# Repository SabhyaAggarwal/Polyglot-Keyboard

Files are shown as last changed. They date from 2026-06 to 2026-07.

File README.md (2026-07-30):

# Polyglot-Keyboard
This is a keyboard made by me that can change between stenography mode and QWERTY mode. It is basically a cheaper version of the [Polyglot Keyboard by Steno Keyboards](https://stenokeyboards.com/products/polyglot-keyboard). It uses the QMK Firmware. The PCB was made in KiCad. The case was designed in OnShape. It is quite effective and also very beautiful. The design and shape are customised for my personal use...

## BOM

|Name |Description |Quantity|Total Cost|Link |Distributor|
|---|---|---|---|---|---|
|PCB |Main PCB(includes payment fee) |1 |$1.36 |https://aivon.com/ |AIVON |
|RP2040 Zero |Main Dev Board(cost includes shipping) |1 |$4.73 |https://robu.in/product/waveshare-rp2040-zero-without-header/ |robu |
|MX Switches |MX switches(pack of 10 and 4 of them = 40 keys and rest 2 keys given by another HackClubber)|4 |$2.86 |https://meckeys.com/shop/accessories/keyboard-accessories/key-switches/regular-switch-3pin/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|meckeys |
|Keycaps |Blank Keycaps(pack of 5) |9 |$8.58 |https://meckeys.com/shop/accessories/keyboard-accessories/keycaps/blank/blank-dsa-keycaps-1u/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 |meckeys |
|1N4148 Diode |1N4148 Diode(price not include shipping as shipping is shared with the RP2040 Zero) |42 |$0.55 |https://robu.in/product/1n4148-1w-zener-diode-pack-of-50/ |robu |
|M3x3mm Heatset Insert|M3 X 3mm Brass Threaded Inserts(includes shipping cost) |3 |$0.94 |https://onlyscrews.in/products/m3-x-3mm-brass-threaded-inserts?variant=49729062273337 |onlyscrews |
|M3x5mm Screws |Screws(shipping grouped with inserts) |3 |$0.06 |https://onlyscrews.in/products/m3-x-5mm-phillips-pan-head-ss-304-screw-dia-3mm-length-5mm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 |onlyscrews |

## Images

### Keymap in Stenography mode

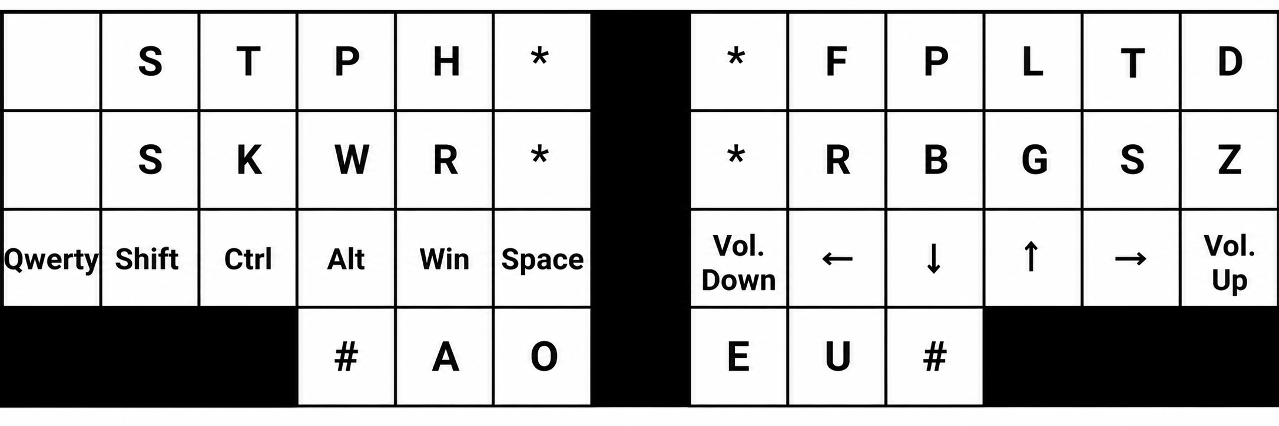
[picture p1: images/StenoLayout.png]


### Keymap in QWERTY mode

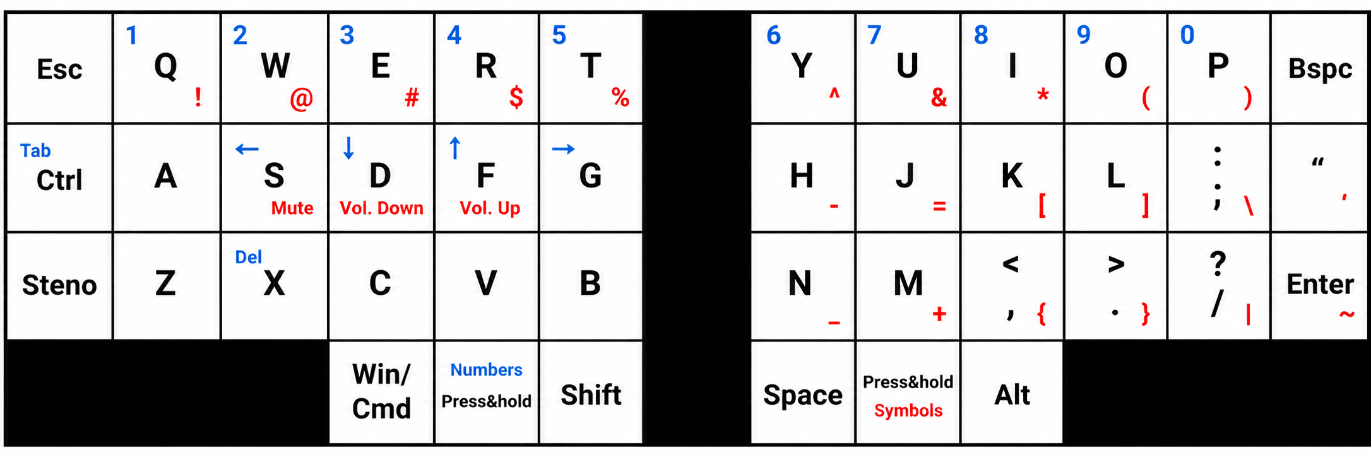
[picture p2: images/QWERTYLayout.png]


### 3D Render of the  assembled keyboard

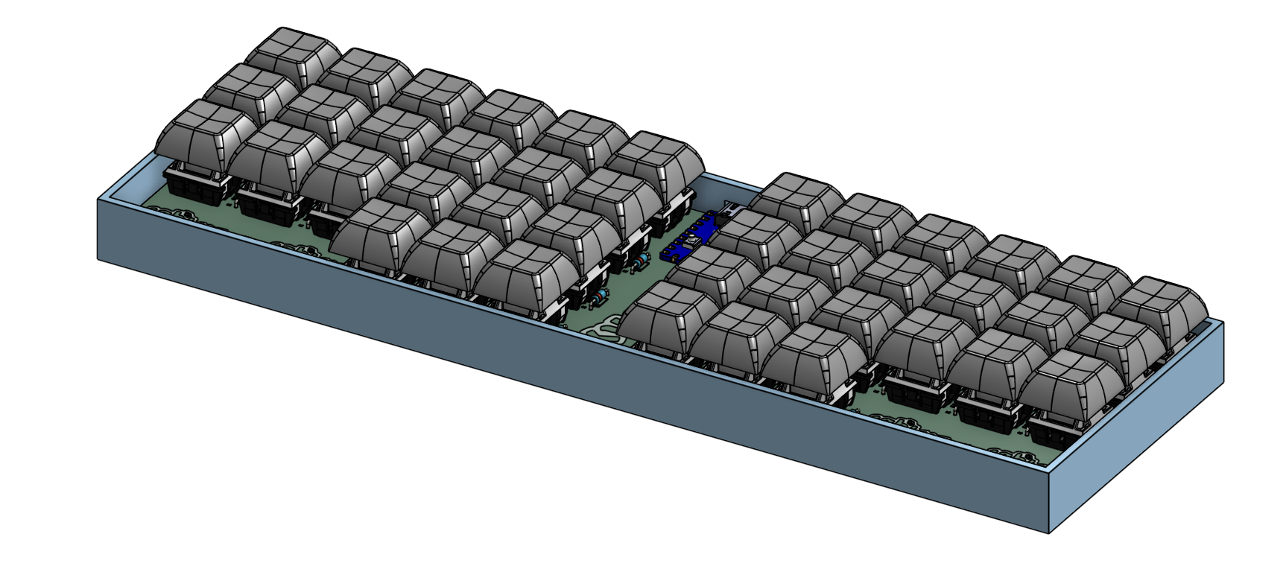
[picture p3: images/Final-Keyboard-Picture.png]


### Case

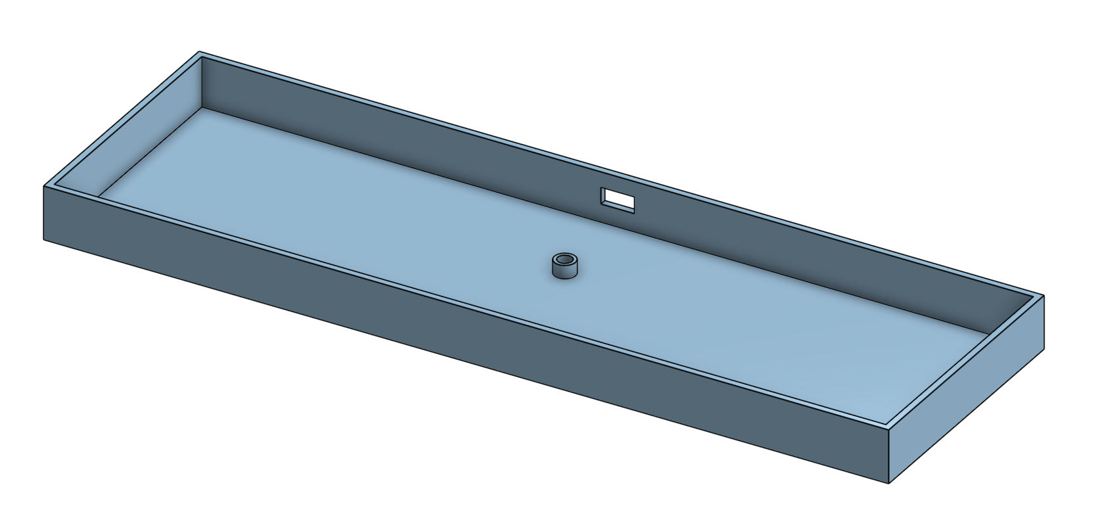
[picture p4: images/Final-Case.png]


#### Note: You can find the OnShape link [here](https://cad.onshape.com/documents/46c4256cf36649b9a784f734/w/7d5e5e40fb0c8f37601f916c/e/410489c67a58600f0a7678ff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)...

### PCB Schematic

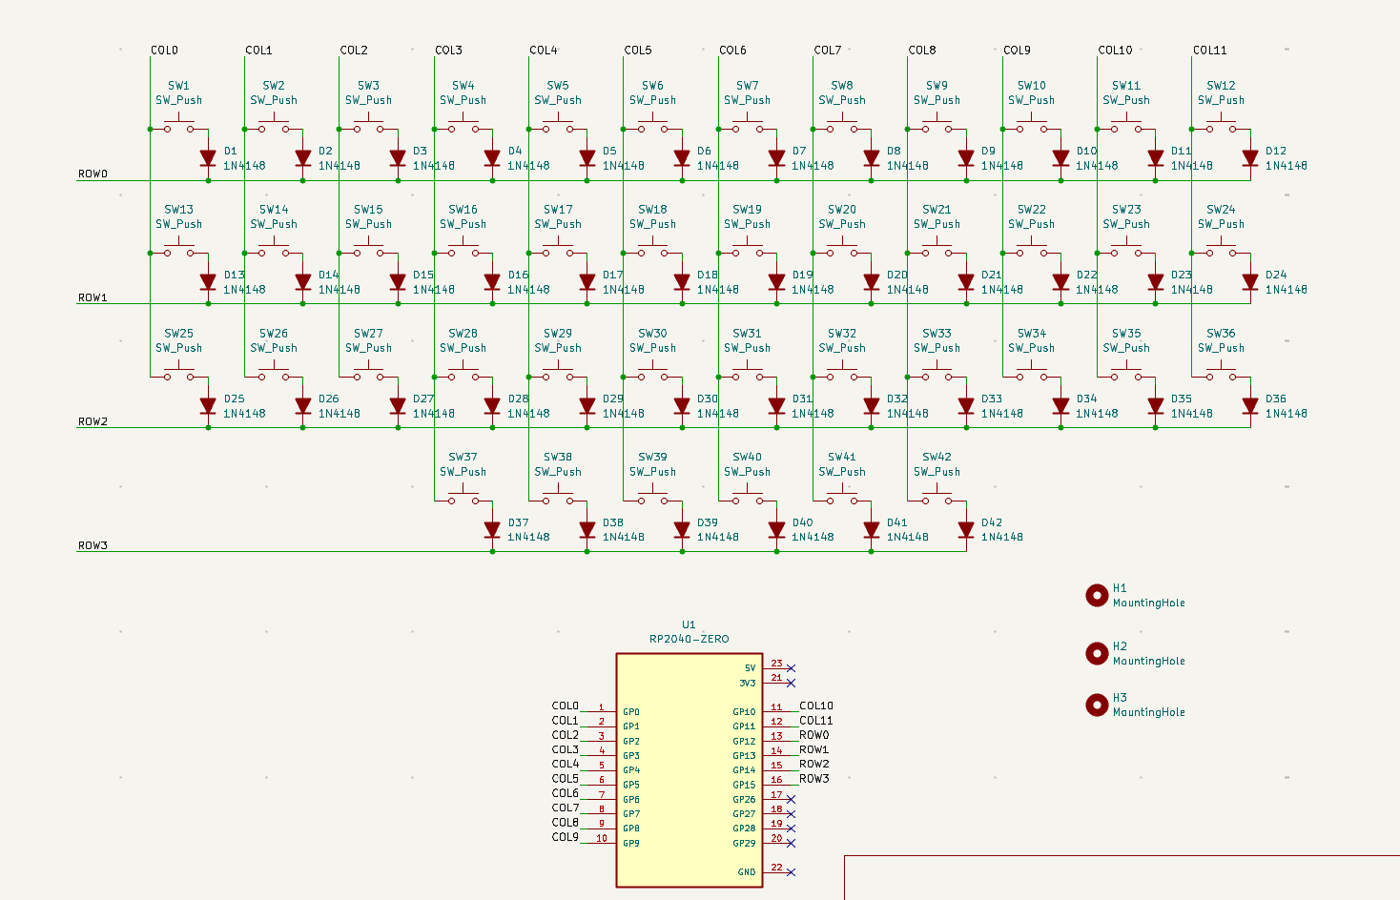
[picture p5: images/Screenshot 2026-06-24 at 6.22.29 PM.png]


### PCB Design

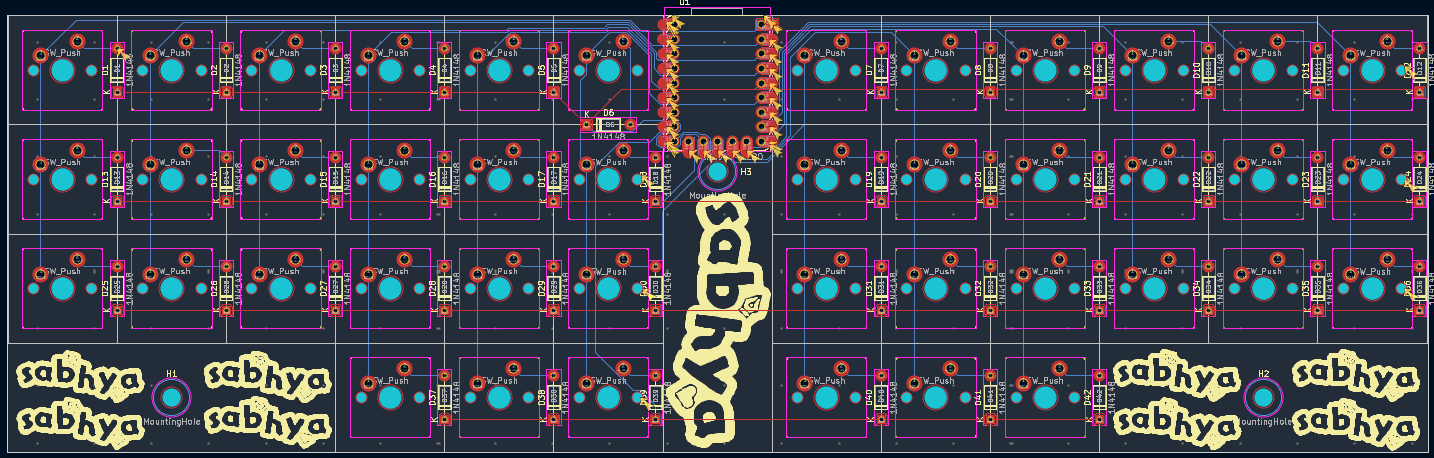
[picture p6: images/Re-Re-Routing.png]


### PCB 3D Render

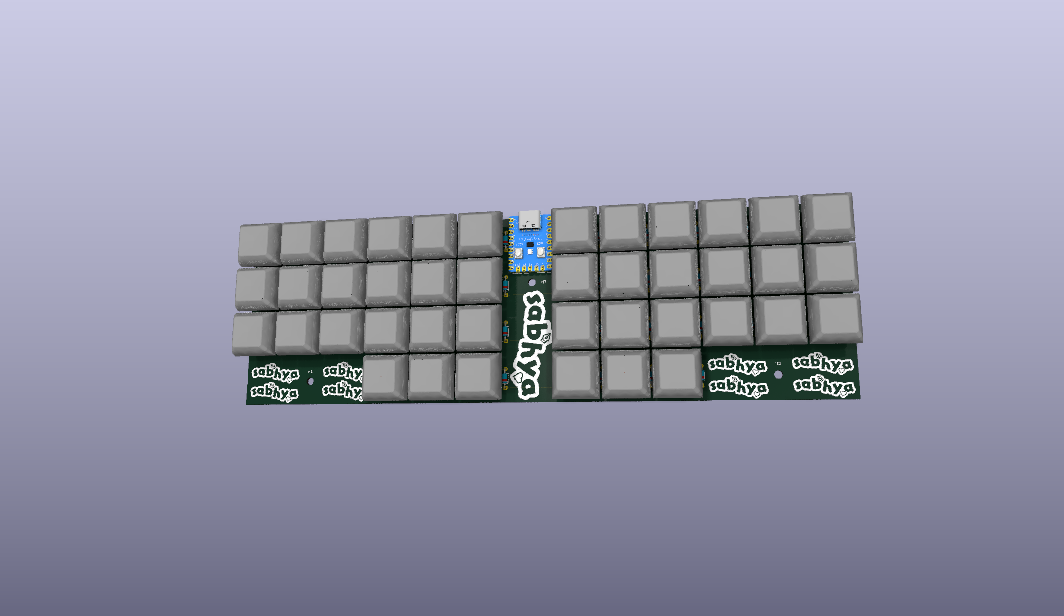
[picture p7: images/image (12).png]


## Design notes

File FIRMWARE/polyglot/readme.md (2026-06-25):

# polyglot

polyglot

*A short description of the keyboard/project*

* Keyboard Maintainer: [Sabhya Aggarwal](https://github.com/SabhyaAggarwal)
* Hardware Supported: *The PCBs, controllers supported*
* Hardware Availability: *Links to where you can find this hardware*

Make example for this keyboard (after setting up your build environment):

    make polyglot:default

Flashing example for this keyboard:

    make polyglot:default:flash

See the [build environment setup](https://docs.qmk.fm/#/getting_started_build_tools) and the [make instructions](https://docs.qmk.fm/#/getting_started_make_guide) for more information. Brand new to QMK? Start with our [Complete Newbs Guide](https://docs.qmk.fm/#/newbs).

## Bootloader

Enter the bootloader in 3 ways:

* **Bootmagic reset**: Hold down the key at (0,0) in the matrix (usually the top left key or Escape) and plug in the keyboard
* **Physical reset button**: Briefly press the button on the back of the PCB - some may have pads you must short instead
* **Keycode in layout**: Press the key mapped to `QK_BOOT` if it is available

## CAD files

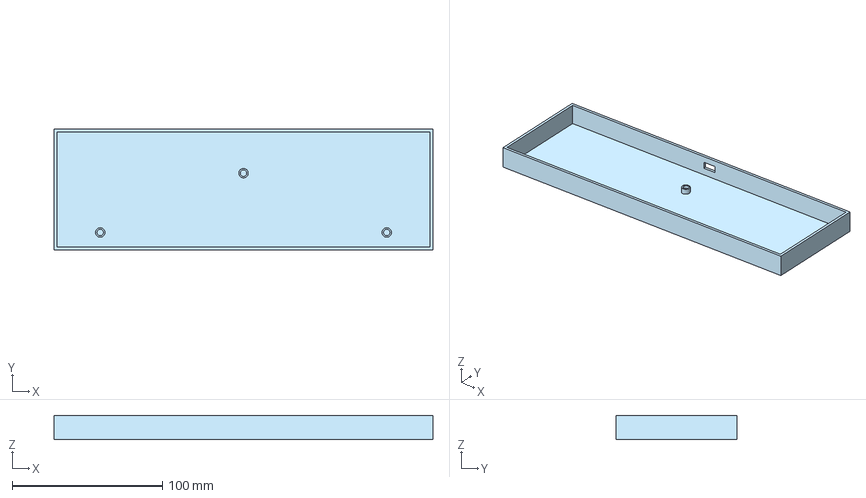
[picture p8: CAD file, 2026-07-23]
CAD/Case.step
252.0 x 80.3 x 16.0 mm

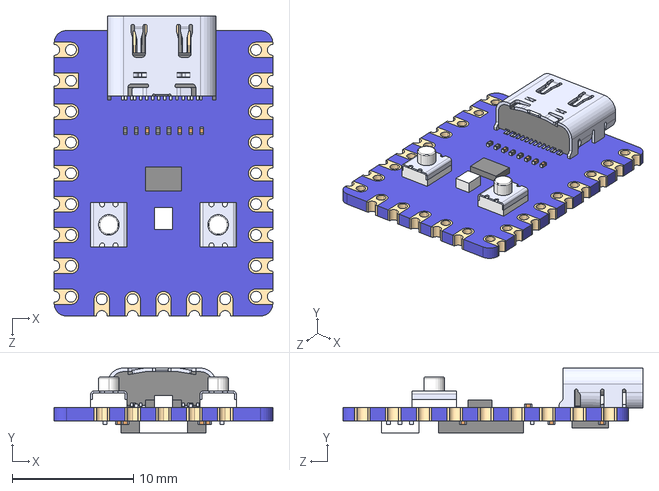
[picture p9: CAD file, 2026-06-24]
PCB/RP2040-ZERO.step
18.0 x 5.35 x 24.7 mm

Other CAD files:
PRODUCTION/Case.stl

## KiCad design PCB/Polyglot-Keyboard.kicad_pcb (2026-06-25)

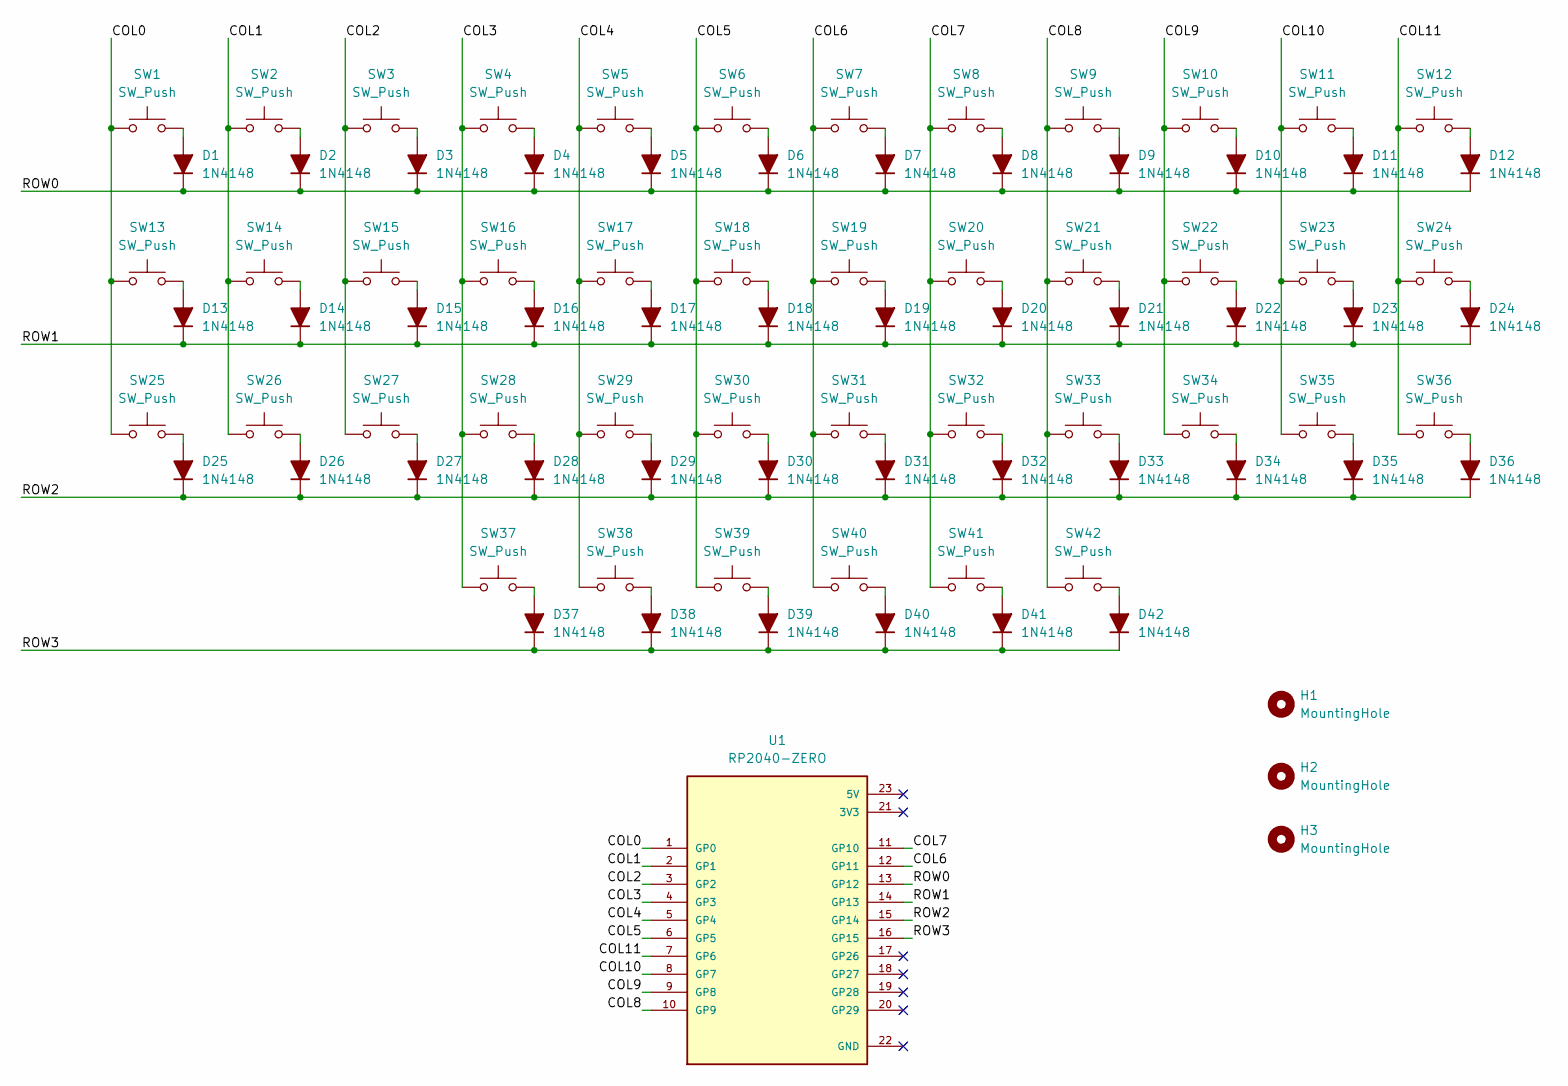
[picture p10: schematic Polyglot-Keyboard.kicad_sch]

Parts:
D1, D2, D3, D4, D5, D6, D7, D8, D9, D10, D11, D12, D13, D14, D15, D16, D17, D18, D19, D20, D21, D22, D23, D24, D25, D26, D27, D28, D29, D30, D31, D32, D33, D34, D35, D36, D37, D38, D39, D40, D41, D42: 1N4148; D_DO-35_SOD27_P7.62mm_Horizontal
H1, H2, H3: MountingHole; MountingHole_3.2mm_M3
SW1, SW2, SW3, SW4, SW5, SW6, SW7, SW8, SW9, SW10, SW11, SW12, SW13, SW14, SW15, SW16, SW17, SW18, SW19, SW20, SW21, SW22, SW23, SW24, SW25, SW26, SW27, SW28, SW29, SW30, SW31, SW32, SW33, SW34, SW35, SW36, SW37, SW38, SW39, SW40, SW41, SW42: SW_Push; SW_MX_1u
U1: RP2040-ZERO; MODULE_RP2040-ZERO; PARTREV NA

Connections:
/COL0: SW1.1, SW13.1, SW25.1, U1.1 (GP0)
/COL1: SW2.1, SW14.1, SW26.1, U1.2 (GP1)
/COL2: SW3.1, SW15.1, SW27.1, U1.3 (GP2)
/COL3: SW4.1, SW16.1, SW28.1, SW37.1, U1.4 (GP3)
/COL4: SW5.1, SW17.1, SW29.1, SW38.1, U1.5 (GP4)
/COL5: SW6.1, SW18.1, SW30.1, SW39.1, U1.6 (GP5)
/COL6: SW7.1, SW19.1, SW31.1, SW40.1, U1.12 (GP11)
/COL7: SW8.1, SW20.1, SW32.1, SW41.1, U1.11 (GP10)
/COL8: SW9.1, SW21.1, SW33.1, SW42.1, U1.10 (GP9)
/COL9: SW10.1, SW22.1, SW34.1, U1.9 (GP8)
/COL10: SW11.1, SW23.1, SW35.1, U1.8 (GP7)
/COL11: SW12.1, SW24.1, SW36.1, U1.7 (GP6)
/ROW0: D1.1 (K), D2.1 (K), D3.1 (K), D4.1 (K), D5.1 (K), D6.1 (K), D7.1 (K), D8.1 (K), D9.1 (K), D10.1 (K), D11.1 (K), D12.1 (K), U1.13 (GP12)
/ROW1: D13.1 (K), D14.1 (K), D15.1 (K), D16.1 (K), D17.1 (K), D18.1 (K), D19.1 (K), D20.1 (K), D21.1 (K), D22.1 (K), D23.1 (K), D24.1 (K), U1.14 (GP13)
/ROW2: D25.1 (K), D26.1 (K), D27.1 (K), D28.1 (K), D29.1 (K), D30.1 (K), D31.1 (K), D32.1 (K), D33.1 (K), D34.1 (K), D35.1 (K), D36.1 (K), U1.15 (GP14)
/ROW3: D37.1 (K), D38.1 (K), D39.1 (K), D40.1 (K), D41.1 (K), D42.1 (K), U1.16 (GP15)
unnamed: D1.2 (A), SW1.2
unnamed: D2.2 (A), SW2.2
unnamed: D3.2 (A), SW3.2
unnamed: D4.2 (A), SW4.2
unnamed: D5.2 (A), SW5.2
unnamed: D6.2 (A), SW6.2
unnamed: D7.2 (A), SW7.2
unnamed: D8.2 (A), SW8.2
unnamed: D9.2 (A), SW9.2
unnamed: D10.2 (A), SW10.2
unnamed: D11.2 (A), SW11.2
unnamed: D12.2 (A), SW12.2
unnamed: D13.2 (A), SW13.2
unnamed: D14.2 (A), SW14.2
unnamed: D15.2 (A), SW15.2
unnamed: D16.2 (A), SW16.2
unnamed: D17.2 (A), SW17.2
unnamed: D18.2 (A), SW18.2
unnamed: D19.2 (A), SW19.2
unnamed: D20.2 (A), SW20.2
unnamed: D21.2 (A), SW21.2
unnamed: D22.2 (A), SW22.2
unnamed: D23.2 (A), SW23.2
unnamed: D24.2 (A), SW24.2
unnamed: D25.2 (A), SW25.2
unnamed: D26.2 (A), SW26.2
unnamed: D27.2 (A), SW27.2
unnamed: D28.2 (A), SW28.2
unnamed: D29.2 (A), SW29.2
unnamed: D30.2 (A), SW30.2
unnamed: D31.2 (A), SW31.2
unnamed: D32.2 (A), SW32.2
unnamed: D33.2 (A), SW33.2
unnamed: D34.2 (A), SW34.2
unnamed: D35.2 (A), SW35.2
unnamed: D36.2 (A), SW36.2
unnamed: D37.2 (A), SW37.2
unnamed: D38.2 (A), SW38.2
unnamed: D39.2 (A), SW39.2
unnamed: D40.2 (A), SW40.2
unnamed: D41.2 (A), SW41.2
unnamed: D42.2 (A), SW42.2

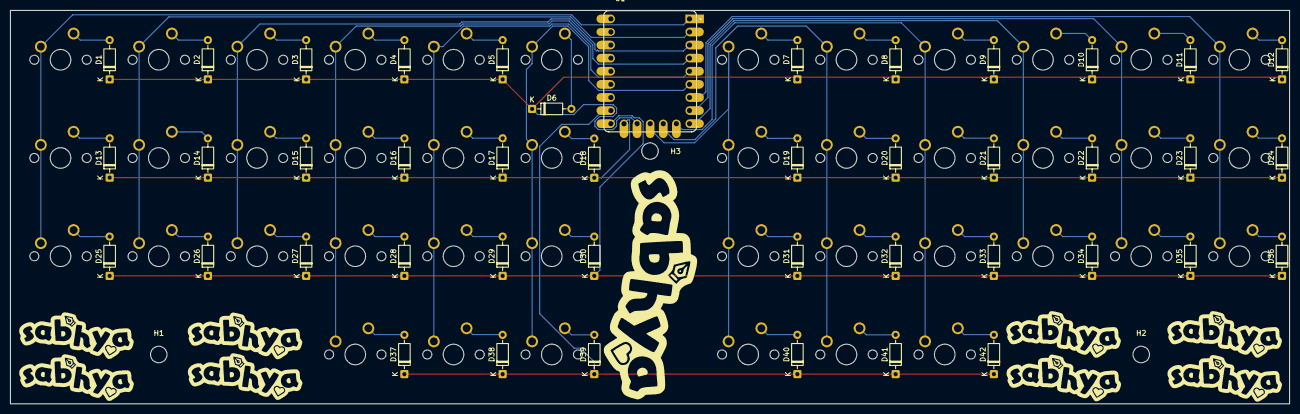
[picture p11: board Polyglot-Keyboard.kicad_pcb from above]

Board: 2 copper layers, 248.0 x 76.3 mm, 88 parts (0 on the bottom side), 58 nets.

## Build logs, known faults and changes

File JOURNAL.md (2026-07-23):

---
title: "Polyglot-Keyboard"
author: "Sabhya Aggarwal"
description: "A keyboard that can function as both a stenography keyboard and a QWERTY keyboard"
created_at: "2026-06-24"
---

# June 24: Made the schematic and PCB

So I explored the guide and decided how I wanted my PCB to be: a mixture of a tray mount and a plateless mount keyboard that supports stenography, which I want to try out, and also supports the QWERTY 

Schematic:

Schematic

and I made the PCB:

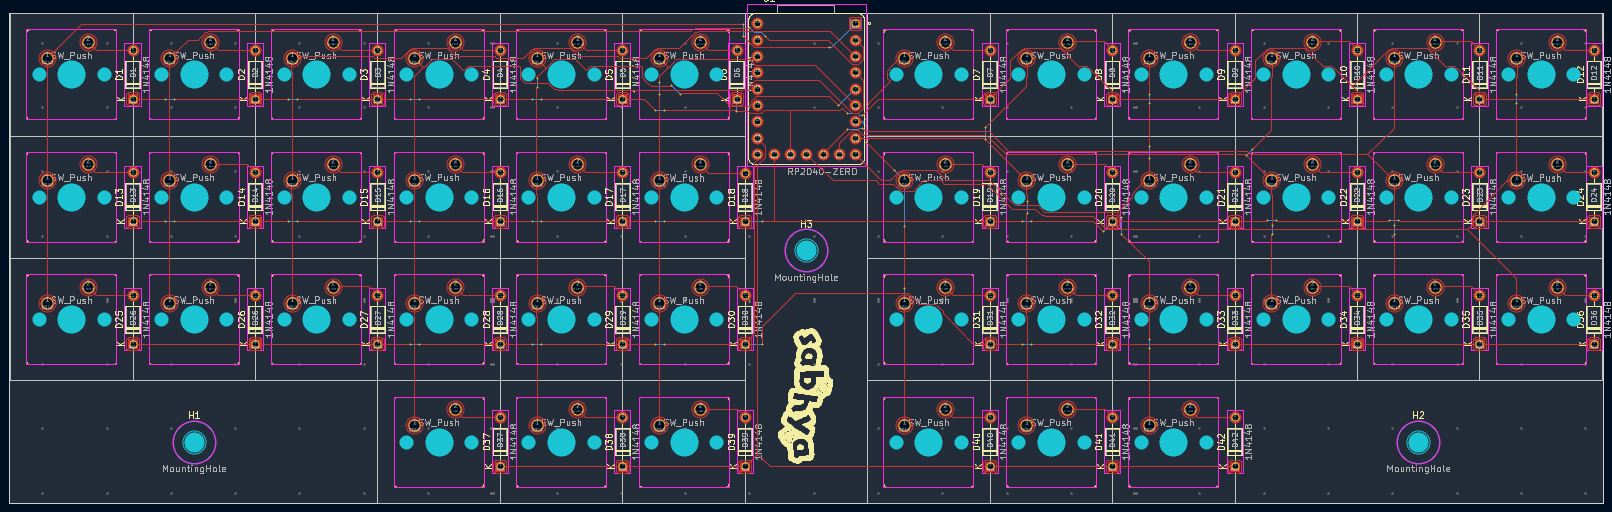
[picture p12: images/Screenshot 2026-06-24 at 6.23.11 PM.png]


Here is the beautiful 3d render of PCB:

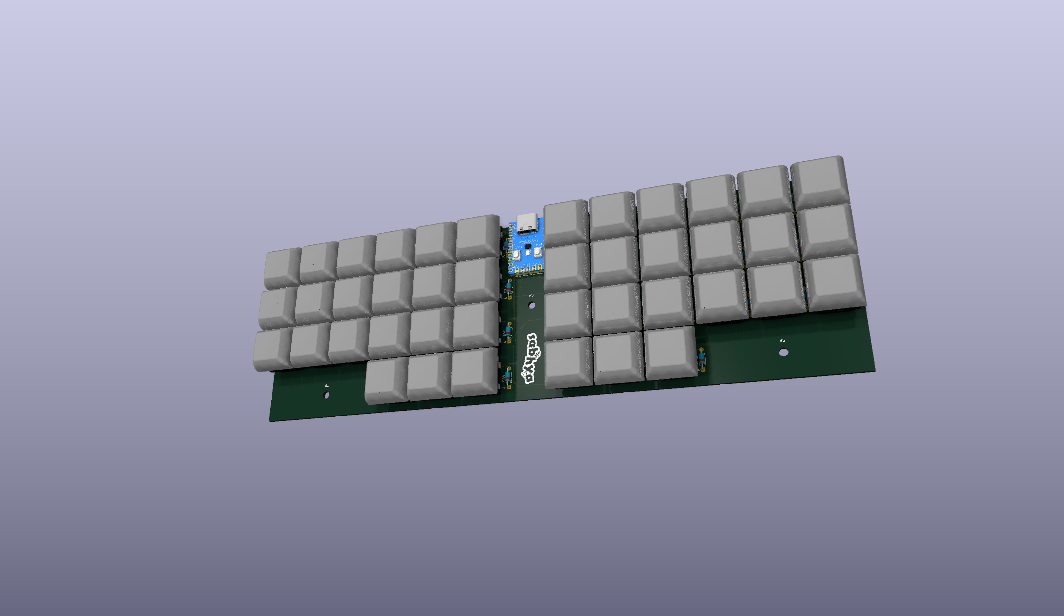
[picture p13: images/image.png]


**Total time spent: 7 hrs**

# June 24: Manually routed the board cleanly

So I found out that auto routing is not allowed so I manually routed everything and I made it cleanly. I had to modify the pinout, which GPIO pins are connected to which, because as I exchanged that I made the routing even cleaner. In the middle I remembered that I can use 2 layers. As I remembered that, I made my routing very beautiful and very good. Now my PCB looks great. I love it 

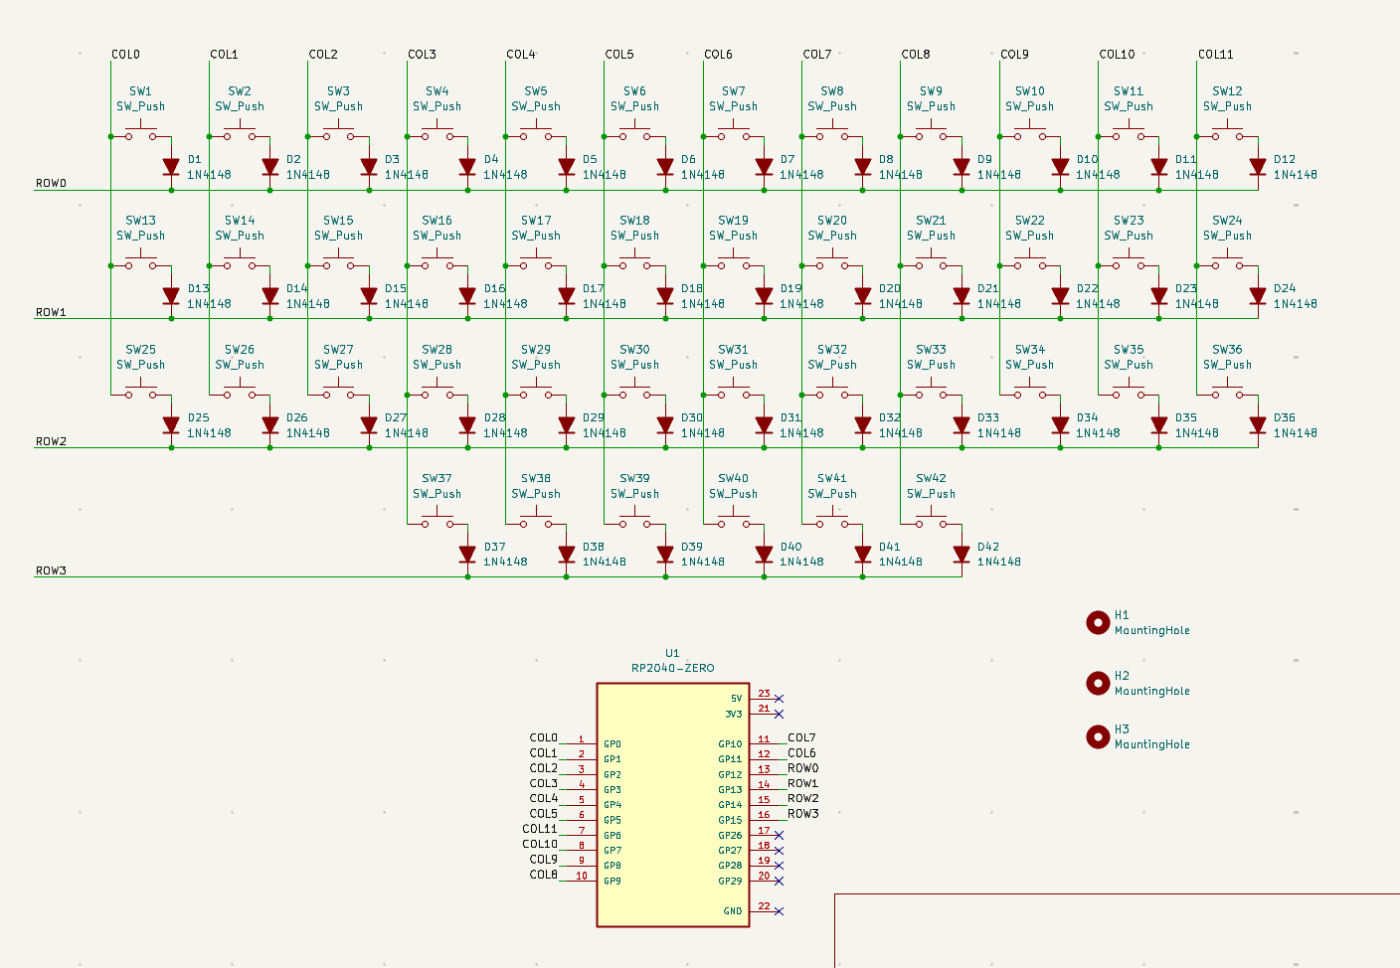
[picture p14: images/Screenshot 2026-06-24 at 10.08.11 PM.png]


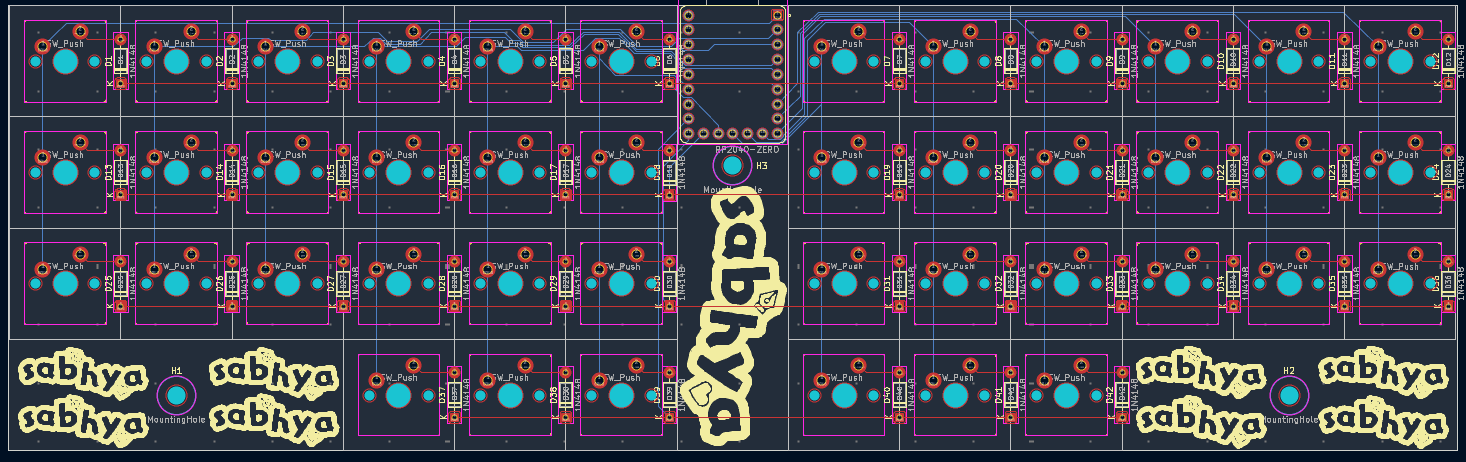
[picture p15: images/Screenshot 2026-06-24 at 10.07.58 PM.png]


3D render

**Total time spent: 3.7 hrs**

# June 25 : Fixed up the routing and all(again) and made Case and Firmware

Today was a really productive day. I decided that I am not going to use other things for the main dev board but rather I'll just directly solder it on through the castellated edges...

Old Footprint:

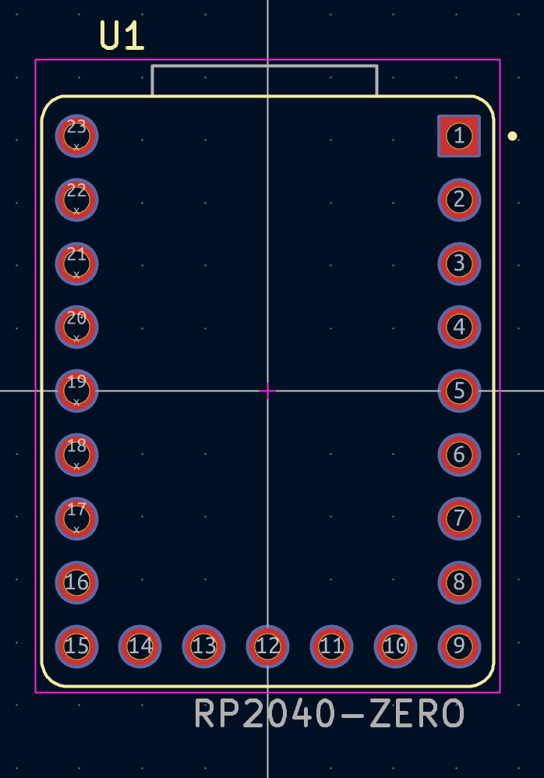
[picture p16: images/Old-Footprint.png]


New footprint:

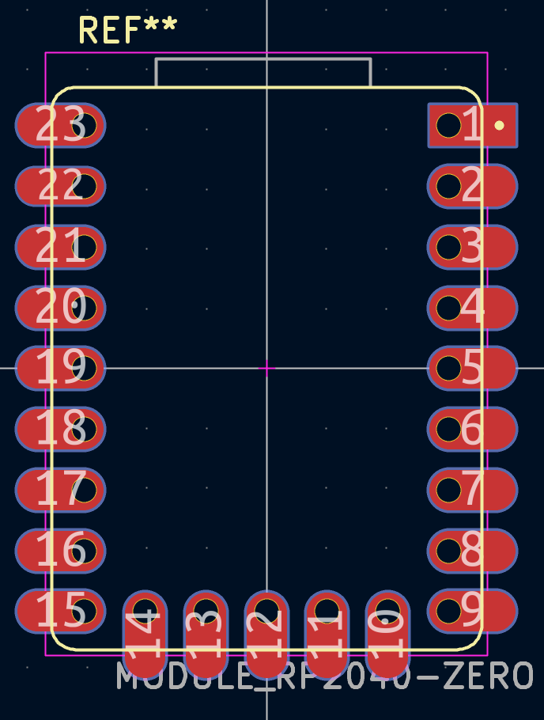
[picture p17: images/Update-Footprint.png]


and I had to re-route as pads became larger:



and I made the case in onshape(the holes at bottom are purposeful, they will help me verify if soldering is still fine if something breaks...):

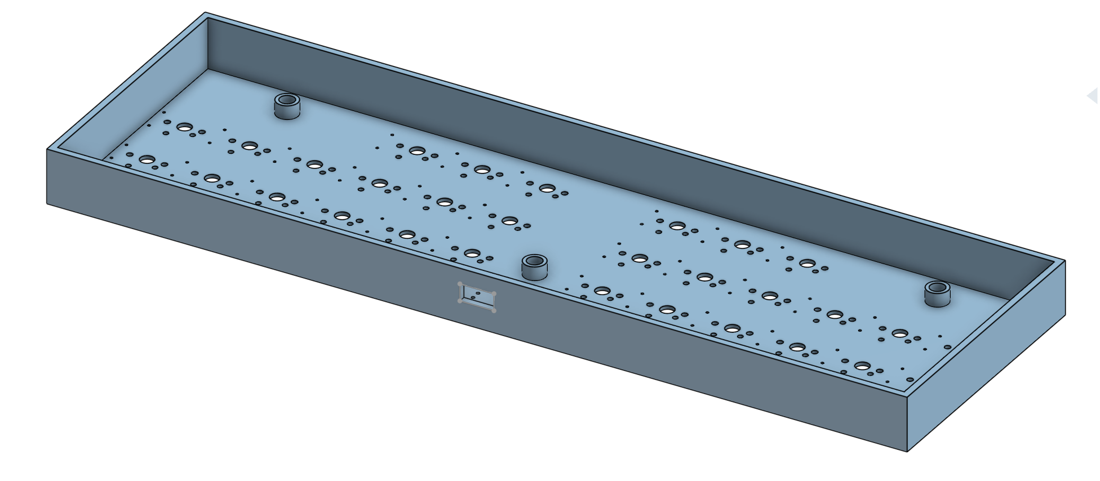
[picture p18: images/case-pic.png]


And the 3d view of my finished keyboard!:

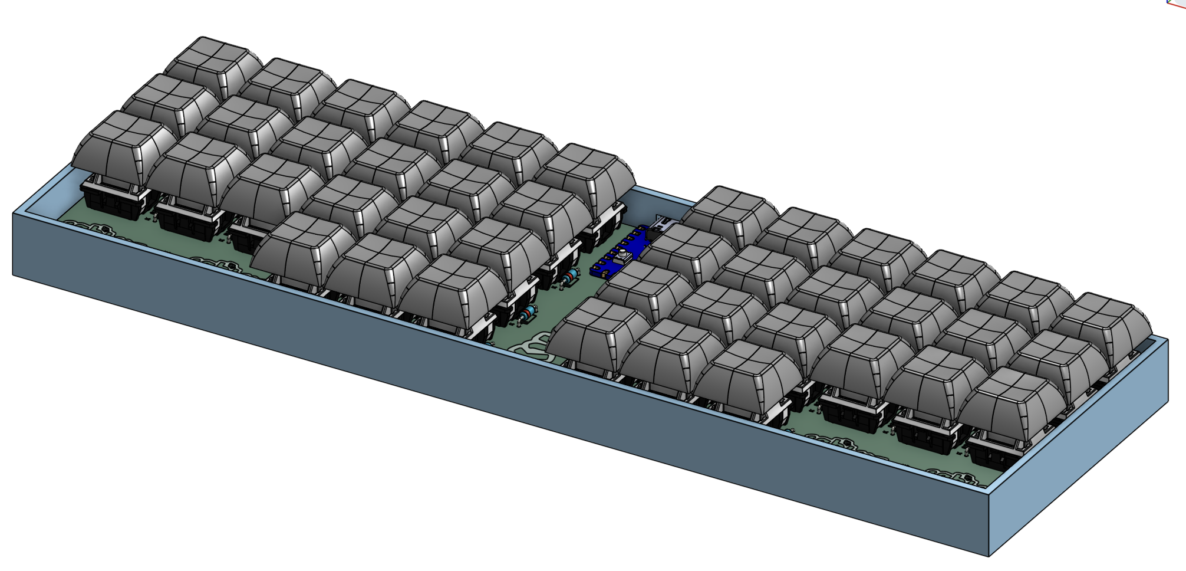
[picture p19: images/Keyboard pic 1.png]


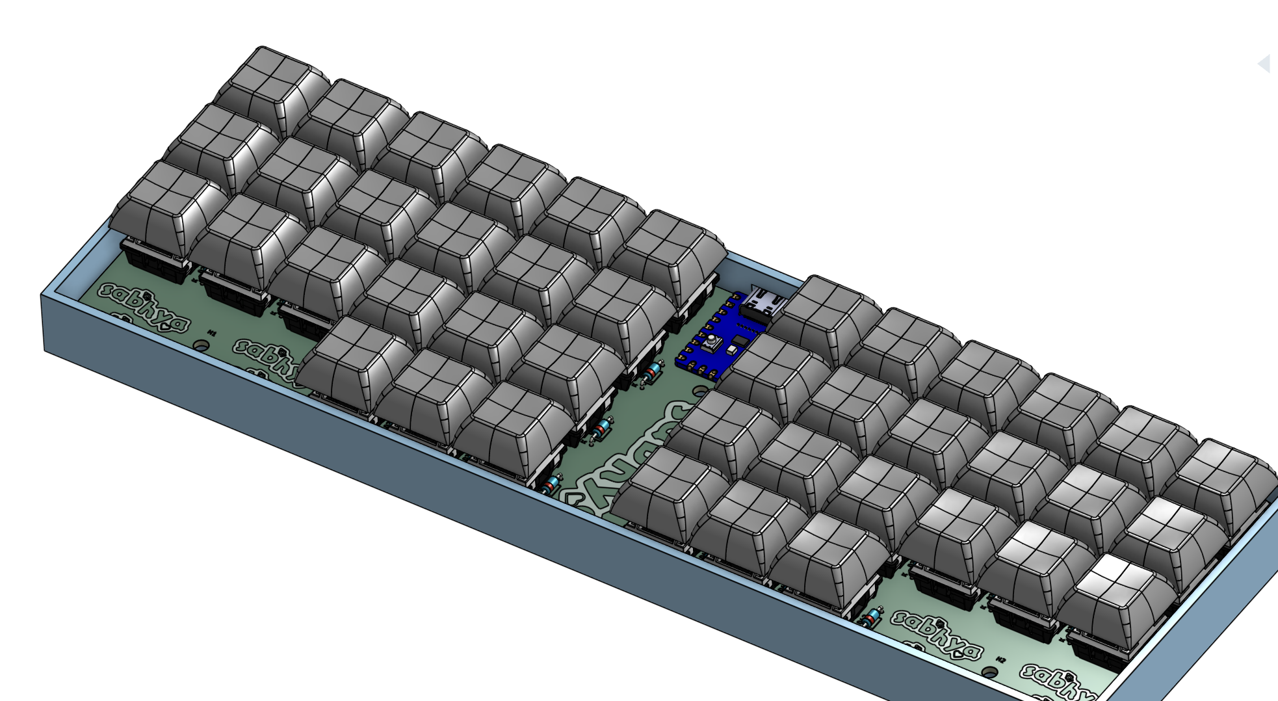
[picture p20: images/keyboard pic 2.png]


and I also made the firmware with QMK

**Total time spent: 8 hrs**

# July 23 : Fixed up the case

I fixed up the case by filling in all the extra holes... it now looks really clean!
New Case:



**Total time spent: 1 hrs**

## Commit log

2026-06-24 Add PCB files and create first journal
    [Polyglot-Keyboard.kicad_pcb, Polyglot-Keyboard.kicad_sch, RP2040-ZERO.step]
2026-06-24 Add some images
    [Polyglot-Keyboard.kicad_pcb, Polyglot-Keyboard.kicad_sch]
2026-06-24 Revise journal entries for June 24 tasks
    Updated journal entries to reflect schematic and PCB work done on June 24, including time spent on each task.
2026-06-25 Add case files and fix PCB
    [Case.stl, Polyglot-Keyboard.kicad_pcb]
2026-06-25 Add Firmware
    [Case.stl, Polyglot-Keyboard.kicad_pcb, Polyglot-Keyboard.kicad_sch]
2026-06-25 Add BOM.csv to PRODUCTION folder
    [BOM.csv]
2026-06-30 Add BOM.csv to root folder
    [BOM.csv, Case Cut.stl, Case.stl]
2026-07-23 Add fixed case files and images and add Journal
    [Case Cut.stl, Case.3mf, Case.step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]
